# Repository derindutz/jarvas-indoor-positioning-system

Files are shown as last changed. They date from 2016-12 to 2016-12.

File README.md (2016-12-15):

# JARVAS Indoor Positioning System

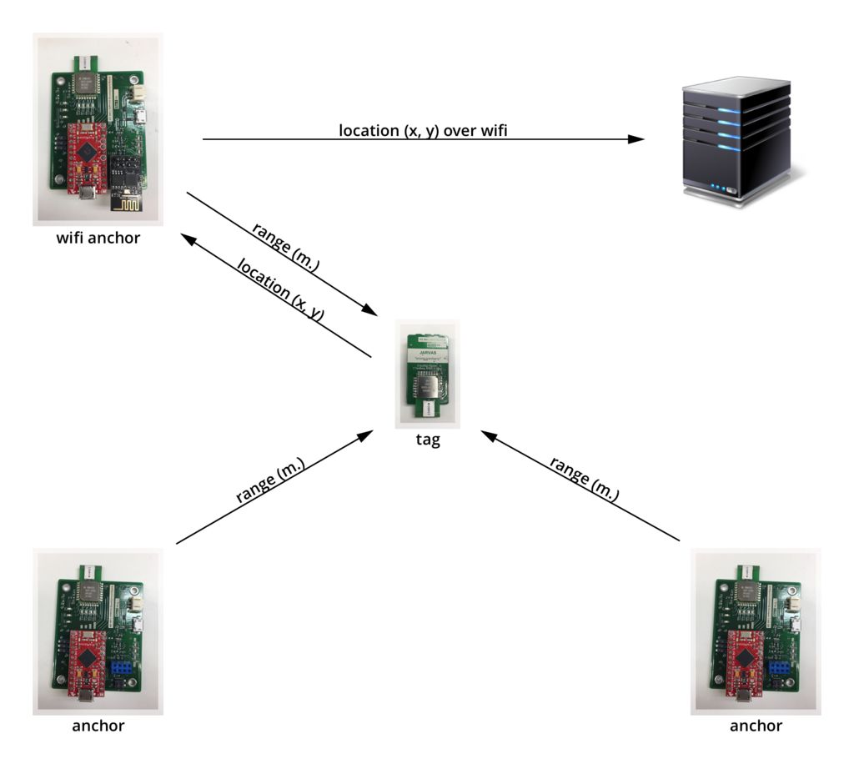
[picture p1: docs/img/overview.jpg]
JARVAS System


JARVAS (Just A Rather Very Average System) is an indoor positioning system, in which a wearable tag communicates with multiple stationary anchors to determine its position.

## How to Build It

Our primary documentation for how to re-create our setup lives on [Instructables](https://www.instructables.com/id/JARVAS-Indoor-Positioning-System/).

## Source Files

All of our source files (including software, PCB design files, and MATLAB simulation code) live in our [GitHub repository](https://github.com/dddutz/jarvas-indoor-positioning-system/).

## Technical Details

This website documents some of the more interesting technical aspects of the project. If you're looking to modify, extend, or get inspiration from what we did, read on.

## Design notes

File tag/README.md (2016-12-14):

# Tag

## Instructions

1. Connect the tag to your computer.
2. Open the .ino file in the Arduino app.
3. Upload the code.

##CALIBRATION IS IMPORTANT!

1. Make sure you know which anchors have which addresses.
2. Set CALIBRATION_FIRST to true.
3. Place each anchor 2 meters away from the tag. Make sure to keep anchors away from each other as much as possible.
4. Record each of the anchor's distance values, and record them in BEACON_N_FIRSTDIST.
5. Repeat this process, but at 5 meters away from each tag, and recording in BEACON_N_SECONDDIST.
5. Set CALIBRATION_FIRST to false.
6. Your tag is now calibrated!

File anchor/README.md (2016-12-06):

# Anchor

## Instructions
1. Connect a non-wifi anchor to your computer.
2. Open the .ino file in the Arduino app.
3. Upload the code.

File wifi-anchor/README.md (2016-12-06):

# Wifi Anchor

## Instructions
1. Connect the wifi anchor to your computer.
2. Open the .ino file in the Arduino app.
3. Upload the code.

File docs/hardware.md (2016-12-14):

# JARVAS Hardware

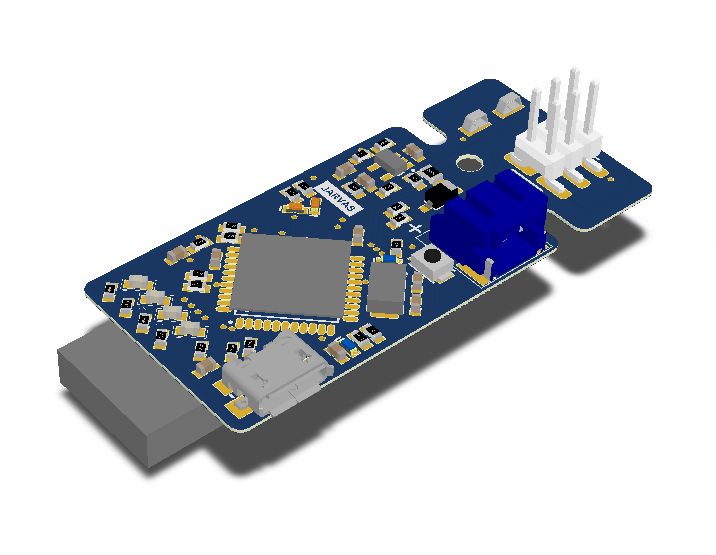
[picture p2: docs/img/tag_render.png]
JARVAS Tag
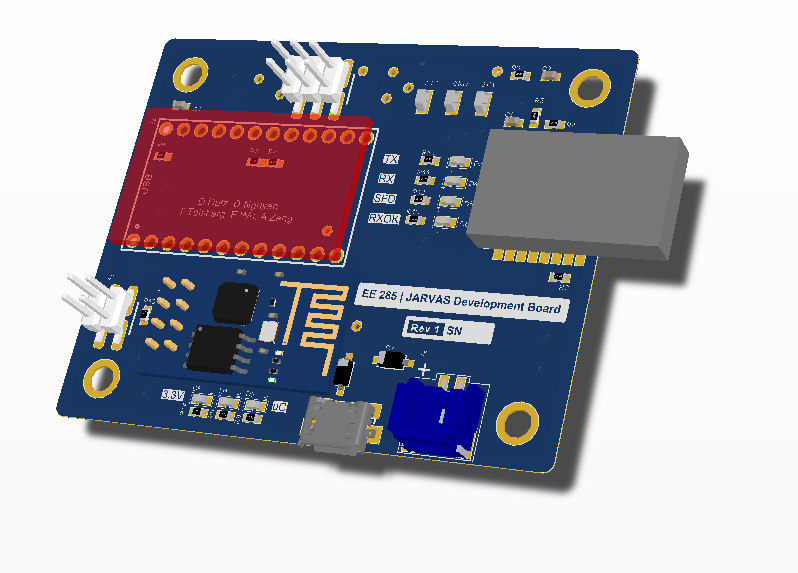
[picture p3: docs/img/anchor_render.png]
JARVAS Anchor


The core of the JARVAS system is the DWM1000 (
[product page](http://www.decawave.com/products/dwm1000-module),
[datasheet](http://www.decawave.com/sites/default/files/resources/dwm1000-datasheet-v1.3.pdf)
) radio module, an ultra wideband transciever module optimized for time of
flight ranging systems, and the Atmega32U4 processor.

There are two versions of the JARVAS hardware: a base station board that
supports WiFi (using an
[ESP8266](https://nurdspace.nl/images/e/e0/ESP8266_Specifications_English.pdf)
) and is designed for easy debugging, and a small, low-cost tag module.
The system requires at least one of the anchors have WiFi support so transmit
location data to a server, however all other anchors and tags in the system
may use either the larger base station board or the small tag board.

## The Tag

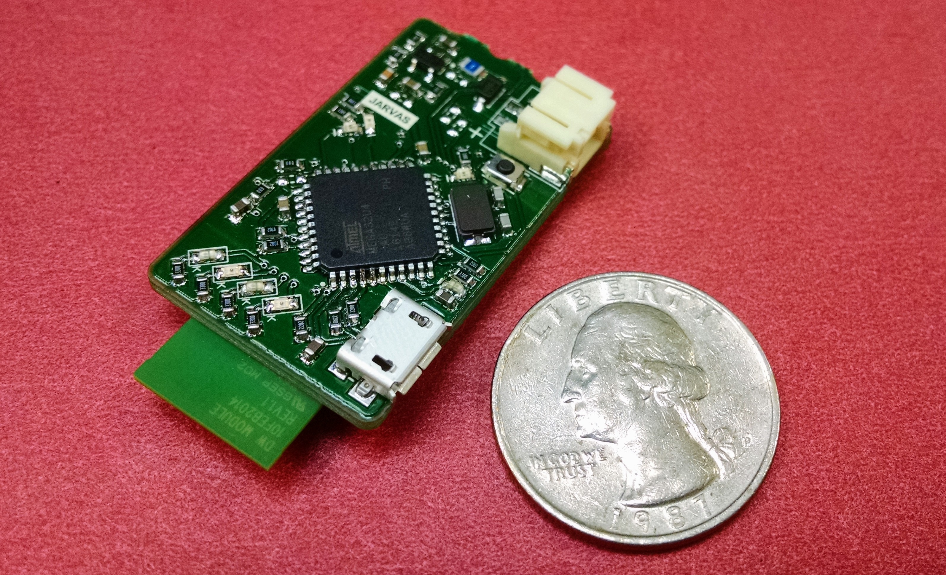
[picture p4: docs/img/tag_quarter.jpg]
JARVAS Tag PCB


The tag board hosts an Atmega32U4, a single-cell LiPo/Li-Ion connector, a few
debugging LEDs, and the DWM1000 radio module. It is essentially a
purpose-built version of the popular [SparkFun Pro Micro](https://www.sparkfun.com/products/12587)
or the [Adafruit Atmega32U4 breakout](https://www.adafruit.com/product/296)
with a DWM1000 module built in.

In total, it measures 1.5"x0.9" without the programming tag.

Note that while we call this this "tag", it is completely capable of being
used as an anchor as well, provided that there is at least one anchor in the
system which supports WiFi.

### Programming Header

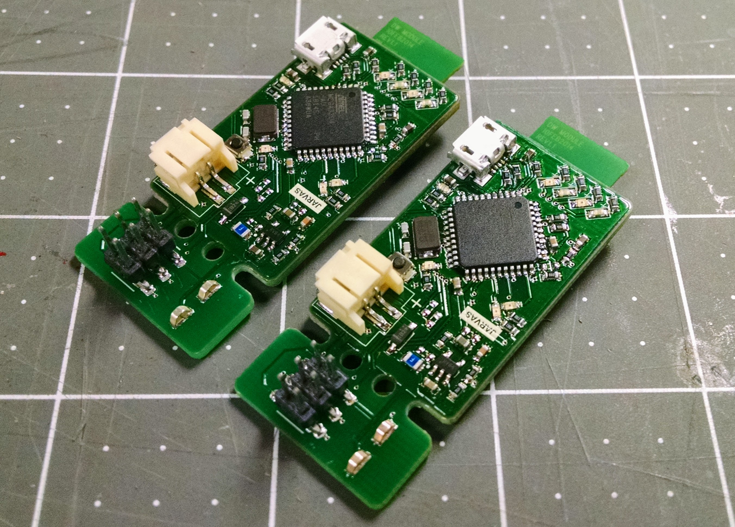
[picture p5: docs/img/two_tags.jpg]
Tags with their programming headers


The tag comes with a break-away section for initial programming. The
section at the top contains test points for the 3.3 V and GND rails and an
ICSP header. This ICSP header can be used to program the Atmega32U4. If you
choose to install the Arduino firmware, as described [here](firmware),
you can program this board directly over USB through the Arduino software.
Once you verify that everythings is working, this top section can be broken
off to reduce the size and height of the PCB.

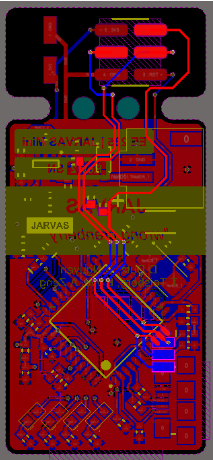
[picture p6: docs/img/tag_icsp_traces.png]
ICSP traces


## The Anchor

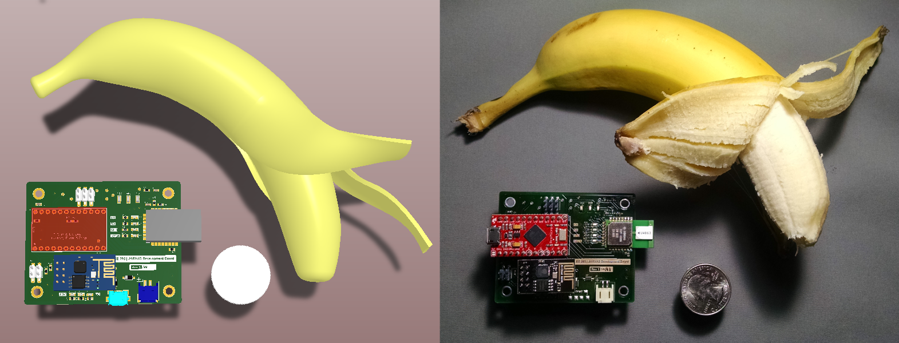
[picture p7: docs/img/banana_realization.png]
An anchor board next to a render


The anchor is the larger, more debug-friendly, and WiFi-supporting version.
It is extremely similar to the tag except for the addition of an ESP8266 WiFi
Module and using an off-the-shelf Arduino Pro Micro instead of having an
Atmega32U4 on-board. This means that no programmer is required to get this
board up and running. The downside, though, is that it is significantly larger
and costs more.

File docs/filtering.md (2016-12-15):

# Filtering

In our testing, we found the ranging data to be quite noisy. With only three anchors, the linear least squares algorithm is quite noise sensitive. As such, some filtering on the ranging data is necessary.

The [Arduino DWM1000 library](https://github.com/thotro/arduino-dw1000) by thotro has a built-in (exponential moving average](https://en.wikipedia.org/wiki/Moving_average#Exponential_moving_average) filter that can be enabled with a single call to `DW1000Ranging.useRangeFilter(true);`. This is a very computationally low-cost choice and definitely a good place to start.

Early on, we took some raw data from pairs of DWM1000 modules in various locations. An example of this data is below:

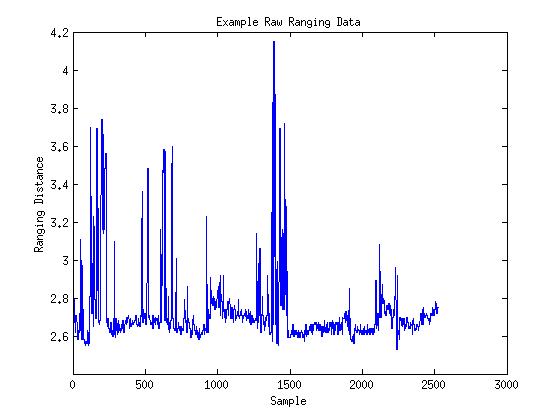
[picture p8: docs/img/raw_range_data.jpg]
Raw ranging data


As you can see, the noise is dominated by sharp peaks lasting only a sample or two. For this type of noise, a median filter is often a more effective choice. While any kind of moving average filter is always going to be affected at least a little by an extremely out of range value, a median filter will allow such valus to slide through without changing output.

Shown below are the results of a simple median filter overlayed in red against another raw data set in black.

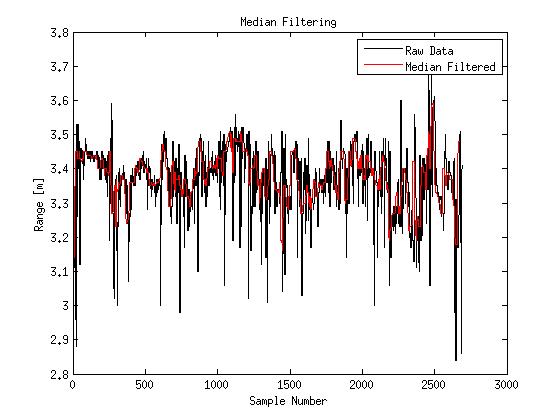
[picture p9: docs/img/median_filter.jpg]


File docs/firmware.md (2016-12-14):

# Programming Arduino Firmware on an Atmega32U4

This page is not really specific to this project and should be useful to anyone trying to program Arduino firmware onto an [Atmega32U4](http://www.atmel.com/Images/Atmel-7766-8-bit-AVR-ATmega16U4-32U4_Datasheet.pdf) chip.

## What you'll need

You will need:

* An ICSP programmer (such as the [JTAGICE3](http://www.atmel.com/tools/jtagice3.aspx))
* The [avrdude](http://www.nongnu.org/avrdude/) software
* Firmware for the chip. We used SparkFun's [Caterina](https://cdn.sparkfun.com/datasheets/Dev/Arduino/Boards/32U4Note.pdf) bootloader (Caterina-promicro8.bin from [here](https://github.com/sparkfun/Arduino_Boards/tree/master/sparkfun/avr/bootloaders/caterina))
* A board with an Atmega32U4 and an ICSP header, such as our [Tag Board](../hardware/#the-tag)

### Tip for Linux users

You may need to setup port permission for your programmer. For the JTAGICE3, you'll need to create a `/etc/udev/rules.d/98-local-jtagice3.rules` file with the following line:

```
SUBSYSTEM=="usb", ATTRS{idVendor}=="03eb", ATTRS{idProduct}=="2140", GROUP="dialout"
```

Also, be sure your user is in the `dialout` group.

## Instructions

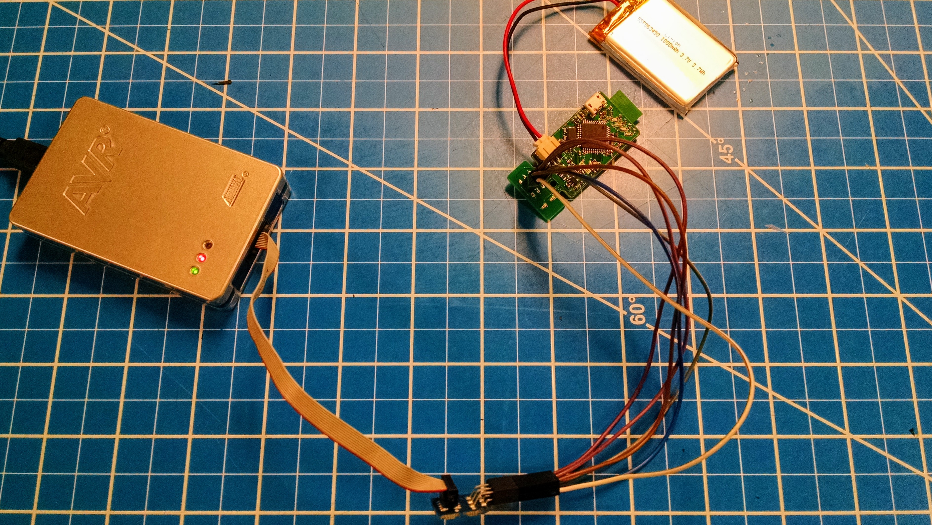
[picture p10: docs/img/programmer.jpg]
JTAGICE3 programmer hooked up to JARVAS tag board


### Step 1: Hook up your programmer

Connect your programmer to the ICSP header on your board. Double check the pinouts and orientations (many ICSP connectors are not keyed) before powering things up.

Remember that your programmer generally does not supply power to the board, so you'll need to supply that yourself.

### Step 2: Test the connection

The following command will read the three sets of fuse bits from the microcontroller and write the values to three text files on your system:

```
avrdude -v -pm32u4 -cjtag3isp -Pusb -B22 -U efuse:r:efuse.hex:h -U hfuse:r:hfuse.hex:h -U lfuse:r:lfuse.hex:h
```

You should get some output that ends with:

```
avrdude: safemode: hfuse reads as 99
avrdude: safemode: efuse reads as F3
avrdude: safemode: Fuses OK (E:F3, H:99, L:5E)

avrdude done.  Thank you.
```

### Step 3: Programming

With the firmware file placed in your working directory, run the following command to set the fuse bits and program your chip:

```
avrdude -v -pm32u4 -cjtag3isp -Pusb -B22 -U flash:w:Caterina-promicro8.hex -U hfuse:w:0xd8:m -U lfuse:w:0xff:m -U efuse:w:0xfe:m
```

It may fail to write the efuse. If prompted, answer 'y' to retry. If it fails, don't worry.

### Step 4: Try it!

Plug your board into your computer over USB and program it with the Arduino software.

## Notes and References

The above commands assume you're using a JTAGICE3 programmer to program an Atmega32U4 clocekd at 8 MHz with a 3.3V supply voltage. If any of those things are not quite the same for you, you'll have to adjust things a bit.

You can find fuse bit settings that go along with the various SparkFun firmwares on [their repository](https://github.com/sparkfun/Arduino_Boards/blob/master/sparkfun/avr/bootloaders/caterina/program.txt).

### Useful References

* [Fuse bit calculator](http://www.engbedded.com/fusecalc/)
* [JTAGICE3 Pinout](http://www.atmel.com/webdoc/jtagice3/jtagice3.using_ocd_physical_spi.html#jtagice3.spi_header_pinout)
* [AVRDUDE Refernce](http://www.nongnu.org/avrdude/user-manual/avrdude_4.html)
* A [blog post](http://electronut.in/bootloader-atmega32u4/) from someone else who has done this

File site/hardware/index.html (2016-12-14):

- Docs »
- Hardware

# JARVAS Hardware

JARVAS Tag JARVAS Anchor

The core of the JARVAS system is the DWM1000 ( product page (http://www.decawave.com/products/dwm1000-module), datasheet (http://www.decawave.com/sites/default/files/resources/dwm1000-datasheet-v1.3.pdf) ) radio module, an ultra wideband transciever module optimized for time of flight ranging systems, and the Atmega32U4 processor.

There are two versions of the JARVAS hardware: a base station board that supports WiFi (using an ESP8266 (https://nurdspace.nl/images/e/e0/ESP8266_Specifications_English.pdf) ) and is designed for easy debugging, and a small, low-cost tag module. The system requires at least one of the anchors have WiFi support so transmit location data to a server, however all other anchors and tags in the system may use either the larger base station board or the small tag board.

## The Tag



The tag board hosts an Atmega32U4, a single-cell LiPo/Li-Ion connector, a few debugging LEDs, and the DWM1000 radio module. It is essentially a purpose-built version of the popular SparkFun Pro Micro (https://www.sparkfun.com/products/12587) or the Adafruit Atmega32U4 breakout (https://www.adafruit.com/product/296) with a DWM1000 module built in.

In total, it measures 1.5"x0.9" without the programming tag.

Note that while we call this this "tag", it is completely capable of being used as an anchor as well, provided that there is at least one anchor in the system which supports WiFi.

### Programming Header



The tag comes with a break-away section for initial programming. The section at the top contains test points for the 3.3 V and GND rails and an ICSP header. This ICSP header can be used to program the Atmega32U4. If you choose to install the Arduino firmware, as described here, you can program this board directly over USB through the Arduino software. Once you verify that everythings is working, this top section can be broken off to reduce the size and height of the PCB.



## The Anchor



The anchor is the larger, more debug-friendly, and WiFi-supporting version. It is extremely similar to the tag except for the addition of an ESP8266 WiFi Module and using an off-the-shelf Arduino Pro Micro instead of having an Atmega32U4 on-board. This means that no programmer is required to get this board up and running. The downside, though, is that it is significantly larger and costs more.

Next Previous

Built with MkDocs (http://www.mkdocs.org) using a theme (https://github.com/snide/sphinx_rtd_theme) provided by Read the Docs (https://readthedocs.org).

« Previous Next »

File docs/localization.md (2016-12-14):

# Localization

JARVAS estimates your position using a linear least squares algorithm based
on time of flight ranging data. On this page, we will break down how this
works in detail.

Imagine you are on a ship and can see a single lighthouse in the distance. 
Let's say you can tell the distance to this lighthouse but nothing else.
If you were looking at a map and knew the location of the lighthouse, you
could draw a circle around the lighthouse and know that you were somewhere
along the circle.

Now let's say you can see a second lighthouse and also your know distance to 
it (but not, let's pretend, the angle between the two lighthouses). Now you
have two circles you can draw. Assuming the two lighthouses are in different
locations, the circles will overlap in one or two locations. Finally, by
adding a third lighthouse, you can figure out which point you are at.

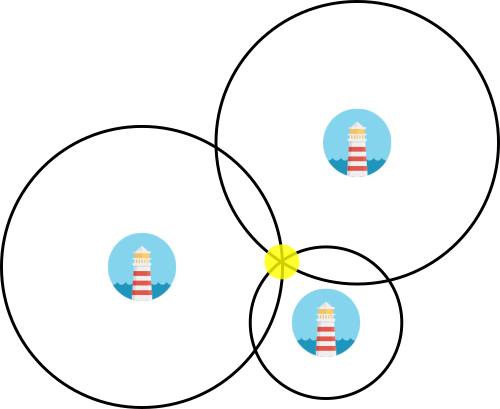
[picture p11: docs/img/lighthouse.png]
Illustration of the light house analogy


Derived from image by pixelbuddha [CC BY 3.0 (http://creativecommons.org/licenses/by/3.0)], via Wikimedia Commons

## Linear Least Squares Estimation

If you aren't familiar with linear least squares estimation, we recommend some
background reading before jumping into this:

[Wikipedia: Linear Least Squares](https://en.wikipedia.org/wiki/Linear_least_squares_(mathematics))

[Stanford Linear Algebra Course Notes](http://ee263.stanford.edu/lectures/ls.pdf)

Our linearized technique is based on the first method described in 
"Linear least squares localization in sensor networks" by Yue Wang (DOI: 
[10.1186/s13638-015-0298-1](http://link.springer.com/article/10.1186/s13638-015-0298-1)).

In general, localization based on a set of distances in a non-linear problem,
however there are linear approximtaions that work quite well.

Each anchor has some known position \((x_i,y_i\) and is can measure a distance
\(\hat{d_i}\) to the tag. For a single anchor \(i\) ranging to a tag at
position \((x,y)\), this
gives us the simple geometric equation:

$$ (x-x_i)^2+(y-y_i)^2=d_i^2 $$

We can then re-arrange this expression as follows:

$$ x^2-2xx_i+x_i^2+y^2-2yy_i+y_i^2=\hat{d}_i^2 \\
-2xx_i - 2yy_i + (x^2+y^2) = \hat{d}_i^2 - x_i^2 - y_i^2 $$

We have three (or more) anchors, so we can write at least three of these
equations. Written in matrix form, we have:

$$
\begin{bmatrix}
-2x_1 & -2y_1 & 1 \\
-2x_2 & -2y_2 & 1 \\
-2x_3 & -2y_3 & 1
\end{bmatrix}
\begin{bmatrix}
x \\
y \\
x^2 + y^2
\end{bmatrix}
=
\begin{bmatrix}
\hat{d}_1^2-x_1^2-y_1^2 \\
\hat{d}_2^2-x_2^2-y_2^2 \\
\hat{d}_3^2-x_3^2-y_3^2
\end{bmatrix}
$$

This gives us the standard form:

$$
\begin{bmatrix}
x \\
y \\
x^2 + y^2
\end{bmatrix}_{ls}
=
\begin{bmatrix}
-2x_1 & -2y_1 & 1 \\
-2x_2 & -2y_2 & 1 \\
-2x_3 & -2y_3 & 1
\end{bmatrix}^\dagger
\begin{bmatrix}
\hat{d}_1^2-x_1^2-y_1^2 \\
\hat{d}_2^2-x_2^2-y_2^2 \\
\hat{d}_3^2-x_3^2-y_3^2
\end{bmatrix}
$$

The left side of the equation is what we want to solve for. Specifically, we are interested in the first two terms of the vector: \(x\) and \(y\).

On the right, the large matrix that we have to take the 
[pseudo-inverse](https://en.wikipedia.org/wiki/Moore%E2%80%93Penrose_pseudoinverse)
of is a function only of the configuration of the system. It changes only if the anchors move, not if the tag moves. This is very important because taking the pseudo-inverse requires a non-trivial number of computations, especially as you start adding more anchors.

At runtime, this works out to be a single matrix-vector multiplication of a 3x3 by a 3x1.

## MATLAB Implementation

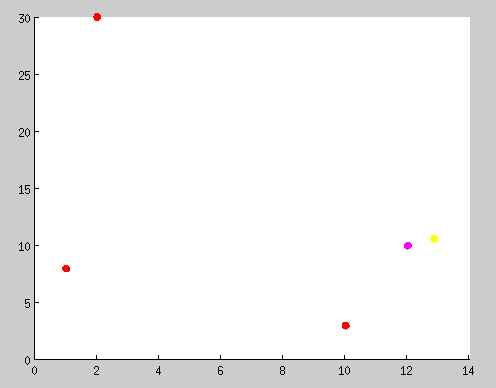
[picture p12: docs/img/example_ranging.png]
Screenshot of MATLAB simulation


In order to test this algorith, we created a MATLAB script that takes in a set of positions and ranges and outputs a graph of the real and estimated location of the tag. If you are intersted in extending this project to use any of several possible better linearized algorithms, this MATLAB script would be a good starting point.

You can find the two MATLAB files `rangepositioning.m` and `plotposition.m` in the [simulation folder](https://github.com/dddutz/jarvas-indoor-positioning-system/tree/master/simulation) of our repository.

## C Implementation

In the JARVAS system, this processing is run on the tag iself. The C implementaiton of this algorithm uses the Arduino MatrixMath library and lives in the [tag sketch](https://github.com/dddutz/jarvas-indoor-positioning-system/blob/master/tag/tag.ino).

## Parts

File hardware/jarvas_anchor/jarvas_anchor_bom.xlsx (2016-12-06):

Description | Customer Refernce | Quantity Per Board | Order Quantity (for 4 boards) | Supplier 1 | Supplier Part Number 1
PC TEST POINT MINIATURE SMT | 3V3, GND, VCC | 3 | 12 | Digi-Key | 5015KCT-ND
 | C1, C2, C3, C4, C7 | 5 | 20 | Digi-Key | 587-1251-1-ND
 | C5 | 1 | 4 | Digi-Key | 587-1441-1-ND
 | C6 | 1 | 4 | Digi-Key | 399-1092-1-ND
Orange 605nm LED Indication - Discrete 2V 0603 (1608 Metric) | D1, D2, D3, D4, D5, D6, D8 | 7 | 28 | Digi-Key | 160-1434-1-ND
DIODE SCHOTTKY 0.5A 20V SOD-123 | D7, D9 | 2 | 8 | Digi-Key | MBR0520LCT-ND
CONN HEADER PH SIDE 2POS 2MM SMD | J2 | 1 | 4 | Digi-Key | 455-1749-1-ND
RF TXRX MODULE WIFI TRACE ANT | J3 | 1 | 4 | Digi-Key | 1568-1235-ND
CONN RCPT MICRO USB AB SMD R/A | J4 | 1 | 4 | Digi-Key | H125279CT-ND
CONN HEADER 6POS .100" VERT TIN | J5 | 1 | 4 | Digi-Key | WM17449-ND
CONN HEADER 4POS .100" VERT TIN | J6 | 1 | 4 | Digi-Key | WM9514-ND
RES SMD 0.0 OHM | R1, R3, R4, R5, R15, R16, R17, R18, R19, R20, R21, R22 | 12 | 48 | Digi-Key | 541-0.0GCT-ND
RES SMD 22K OHM 1% 1/10W 0603 | R2 | 1 | 4 | Digi-Key | 541-22.0KHCT-ND
RES SMD 47K OHM 1% 1/10W 0603 | R6, R7 | 2 | 8 | Digi-Key | 541-47.0KHCT-ND
RES SMD 330 OHM 1% 1/10W 0603 | R8, R9, R10, R11, R12, R13, R14 | 7 | 28 | Digi-Key | 541-330HCT-ND
Linear Voltage Regulator IC Positive Fixed 1 Output 3.3V 500mA TSOT-23-5 | U2 | 1 | 4 | Digi-Key | CAT6219-330TDGT3CT-ND
12 Pin Female Header | J1 | 2 | 8 | Digi-Key | 609-3553-ND
SparkFun Arduino Pro Micro | Pro Micro | 1 | 4 | Digi-Key | 1568-1061-ND
Solder Paste | PASTE | 1 | 1 | Digi-Key | SMD291AX50T3-ND

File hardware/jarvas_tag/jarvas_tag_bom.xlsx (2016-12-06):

Comment | Description | Designator | Per Board | Supplier Part Number | Order Quantity | Customer Reference
TEST_KEYSTONE5015 | PC TEST POINT MINIATURE SMT | 3V3, GND | 2 | 5015KCT-ND | 8 | Jarvas Mini 3V3, GND
__template_cap |  | C1, C2, C3, C6, C10 | 5 | 587-1251-1-ND | 20 | Jarvas Mini C1, C2, C3, C6, C10
__template_cap |  | C4 | 1 | 587-1441-1-ND | 4 | Jarvas Mini C4
__template_cap |  | C5 | 1 | 399-1092-1-ND | 4 | Jarvas Mini C5
__template_cap |  | C7 | 1 | 478-1251-1-ND | 4 | Jarvas Mini C7
CAP_CER_8PF_100V |  | C8, C9 | 2 | 478-3697-1-ND | 8 | Jarvas Mini C8, C9
LED | Green LED | D1, D2, D6, D7, D8, D9 | 6 | LTST-C191KGKT | 24 | Jarvas Mini D1, D2, D6, D7, D8, D9
LED_LBQ39G_BLUE | Blue 470nm LED Indication - Discrete 2.85V 0603 (1608 Metric) | D3, D4 | 2 | 475-2816-1-ND | 8 | Jarvas Mini D3, D4
SCHOTTKY_MBR0520L | DIODE SCHOTTKY 0.5A 20V SOD-123 | D5 | 1 | MBR0520LCT-ND | 4 | Jarvas Mini D5
FAST_MFU0805.50CT-ND | FUSE .50A 0805 VFAST SMD | F1 | 2 | MFU0805.50CT-ND | 8 | Jarvas Mini F1
CONN_USB_MICROAB_SMD_R/A | CONN RCPT MICRO USB AB SMD R/A | J1 | 1 | H125279CT-ND | 4 | Jarvas Mini J1
CONN JST 2POS SMD | CONN HEADER PH SIDE 2POS 2MM SMD | J2 | 1 | 455-1749-1-ND | 4 | Jarvas Mini J2
CONN_2x3_15-91-2060 | CONN HEADER 6POS .100" VERT TIN | J3 | 1 | WM17449-ND | 4 | Jarvas Mini J3
__template_resistor | RES SMD 47K OHM 1% 1/10W 0603 | R1, R6, R8 | 3 | 541-47.0KHCT-ND | 12 | Jarvas Mini R1, R6, R8
__template_resistor | RES SMD 10K OHM 1% 1/10W 0603 | R2, R13 | 2 | 541-10.0KHCT-ND | 8 | Jarvas Mini R2, R13
__template_resistor | RES SMD 0.0 OHM | R3, R4, R5, R7, R17 | 5 | 541-0.0GCT-ND | 20 | Jarvas Mini R3, R4, R5, R7, R17
__template_resistor | RES SMD 330 OHM 1% 1/10W 0603 | R9, R10, R14, R15, R18, R19, R20, R21 | 8 | 541-330HCT-ND | 32 | Jarvas Mini R9, R10, R14, R15, R18, R19, R20, R21
__template_resistor | RES SMD 22 OHM 1% 1/10W 0603 | R11, R12, R22, R23, R24 | 5 | 541-22.0HCT-ND | 20 | Jarvas Mini R11, R12, R22, R23, R24
__template_resistor | RES SMD 22K OHM 1% 1/10W 0603 | R16 | 1 | 541-22.0KHCT-ND | 4 | Jarvas Mini R16
SWITCH_SPST-NO | SWITCH TACTILE SPST-NO 0.05A 12V | SW1 | 1 | SW1020CT-ND | 4 | Jarvas Mini SW1
MCU_ATMEGA32U4 | IC MCU 8BIT 32KB FLASH 44TQFP | U1 | 1 | ATMEGA32U4-AURCT-ND | 4 | Jarvas Mini U1
3.3V LDO | Linear Voltage Regulator IC Positive Fixed 1 Output 3.3V 500mA TSOT-23-5 | U2 | 1 | CAT6219-330TDGT3CT-ND | 4 | Jarvas Mini U2
DWM1000 |  | U3 | 1 | 1479-1002-1-ND | 1 | Jarvas Mini U3
XTAL_NX5032GA | CRYSTAL 8.00 MHZ 8PF SMD | X1 | 1 | 644-1132-1-ND | 4 | Jarvas Mini X1

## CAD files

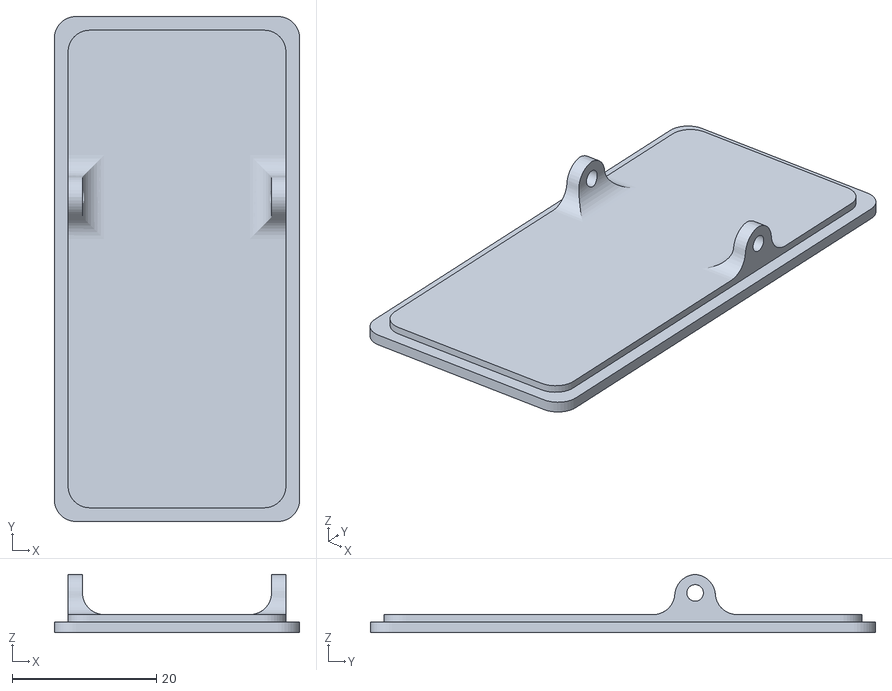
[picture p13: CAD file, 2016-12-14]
3D Files/jarvas_box lid.STL
34.0 x 70.0 x 8.07

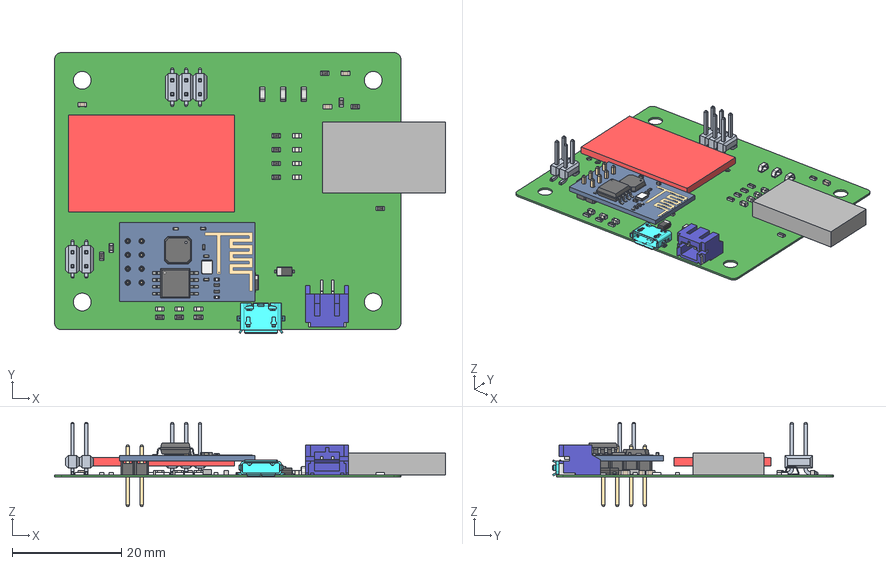
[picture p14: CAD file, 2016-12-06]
hardware/jarvas_anchor/jarvas_anchor_cad.step
71.7 x 51.5 x 15.4 mm
Board
ZX62-AB-5PA
User_Library-Wi07C
keystone5015 x 3
Extruded x 24
CircuitWorks-SOD123 x 2
S2B-PH-SM4-TB

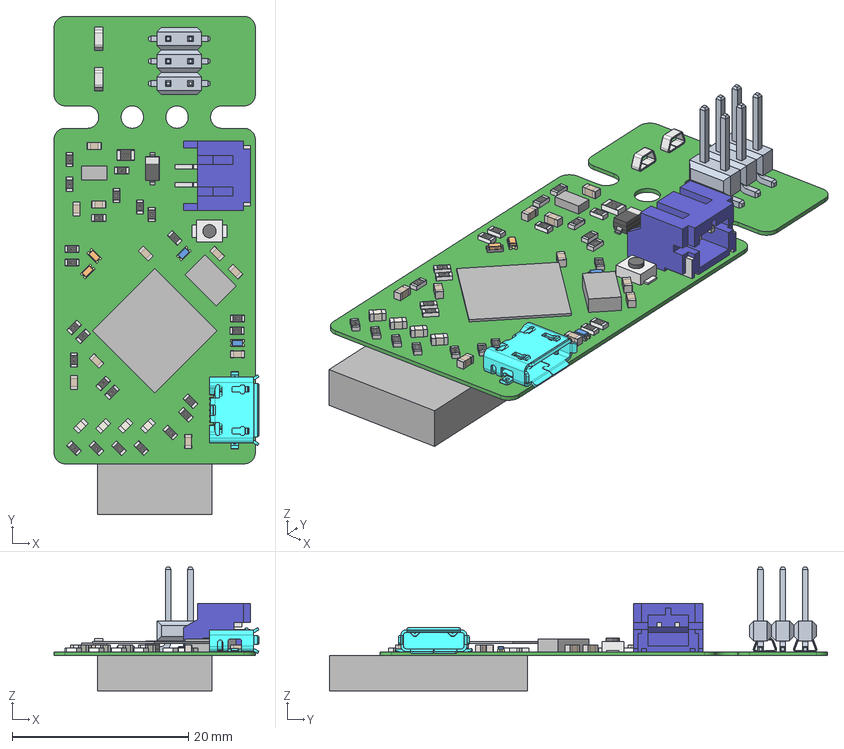
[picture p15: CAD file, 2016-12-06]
hardware/jarvas_tag/jarvas_tag_cad.step
23.3 x 56.6 x 14.1 mm
Board
keystone5015 x 2
User_Library-led_0603_(4) x 2
User_Library-led_0603_(2) x 2
CircuitWorks-SOD123
Extruded x 16
ZX62-AB-5PA
S2B-PH-SM4-TB
b3u-1000p

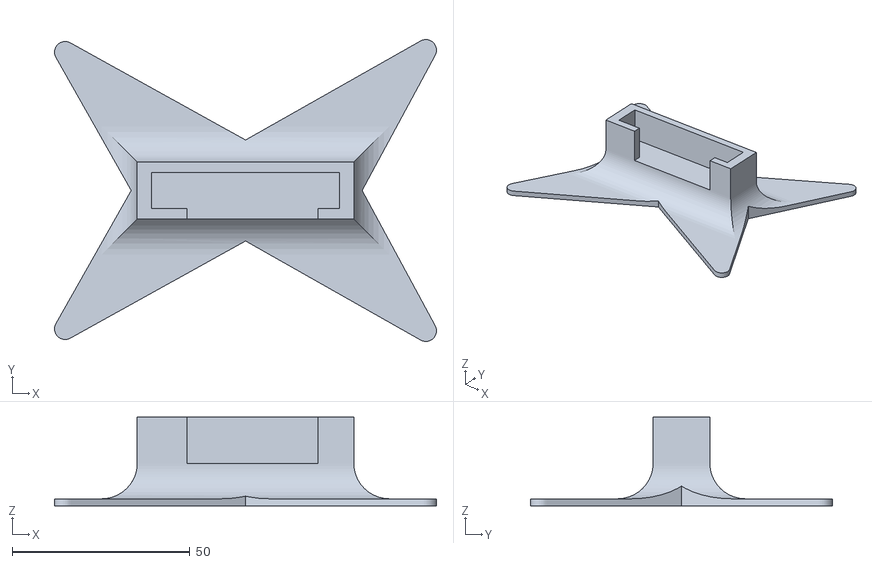
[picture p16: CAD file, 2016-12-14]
3D Files/jarvas_stand.STL
107.6 x 85.0 x 25.0

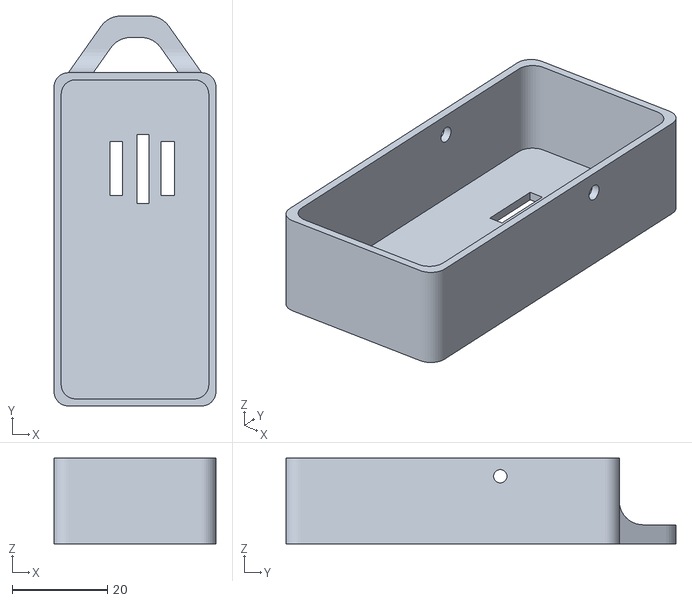
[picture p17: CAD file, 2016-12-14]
3D Files/jarvas_box.STL
34.0 x 81.9 x 18.0

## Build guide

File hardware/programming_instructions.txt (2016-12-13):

Programming the SparkFun Caterina bootloader onto an Atmega32U4
Written: 2016-11-14
Updated: 2016-12-13

This process probably needs to be optimized and refined, but the following appears to work. This was tested on Linux (Ubuntu 16.04), but should be portable to any platform.

If you are using a part other than the Atmega32U4 or a clock frequency other than 8 MHz, be sure to follow the instructions to download the correct firmware and find the correct fuse settings. If you are using a programmer other than the AVR JTAGICE3, be sure to update the "-cjtag3isp" argument.

*** Permissions ***

For Linux:
Create /etc/udev/rules.d/98-local-jtagice3.rules with the following line:
SUBSYSTEM=="usb", ATTRS{idVendor}=="03eb", ATTRS{idProduct}=="2140", GROUP="dialout"

*** Firmware ***

Get the firmware from here: https://github.com/sparkfun/Arduino_Boards/tree/master/sparkfun/avr/bootloaders/caterina
The correct one for an 8MHz Atmega32U4 is Caterina-promicro8.hex
The program.txt file has the fuse bit settings you need

*** Programming ***

Step 0: Read fuses to file
(This isn't technically necessary, but it's good just to confirm that you can talk to the chip.)
avrdude -v -pm32u4 -cjtag3isp -Pusb -B22 -U efuse:r:efuse.hex:h -U hfuse:r:hfuse.hex:h -U lfuse:r:lfuse.hex:h

Output should end with:
-----------------------------------------------------
avrdude: safemode: hfuse reads as 99
avrdude: safemode: efuse reads as F3
avrdude: safemode: Fuses OK (E:F3, H:99, L:5E)

avrdude done.  Thank you.
-----------------------------------------------------

It will also create three files in your working directory (efuse.hex, hfuse.hex, and lfuse.hex) that contain the current fuse settings. See fuse_bits_example/before for example output of this command before you configure the fuses in Step 1 (below) and fuse_bits_example/after for what you should have after Step 1.

Step 1:
avrdude -v -pm32u4 -cjtag3isp -Pusb -B22 -U flash:w:Caterina-promicro8.hex -U hfuse:w:0xd8:m -U lfuse:w:0xff:m -U efuse:w:0xfe:m
Answer 'y' at the prompt. Don't worry if it says the efuse could not be changed.

That's it!

*** Useful references ***

Looking up fuse bits: http://www.engbedded.com/fusecalc/
Someone else who did this: http://electronut.in/bootloader-atmega32u4/
AVRDUDE reference: http://www.nongnu.org/avrdude/user-manual/avrdude_4.html
JTAGICE3 SPI pinout: http://www.atmel.com/webdoc/jtagice3/jtagice3.using_ocd_physical_spi.html#jtagice3.spi_header_pinout

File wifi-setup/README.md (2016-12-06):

# Wifi Setup

## Instructions
1. Connect the wifi anchor to your computer.
2. Open the .ino file in the Arduino app.
3. Upload the code.
4. Once the code is uploaded, open the Serial Monitor.
5. Type AT into the Serial Monitor. You should see OK returned.
6. Type AT+CWMODE=1 into Serial. You should see OK returned.
7. Type AT+CWLAP into Serial. You should see a list of access points. Note that the ssid you want to use is in the list.
8. Type AT+CWJAP="ssid","pwd" where ssid is the one you want to use and pwd is the corresponding password.
9. Once you've recieved an IP, type AT+CIFSR. You should see a valid IP address returned.

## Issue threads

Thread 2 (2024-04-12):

using pcbway for assembly

ilker-aktuna, 2024-04-12:
Hi,

This is a very nice project and I would really like to use it at home for some smarthome projects.
But I am not good at assembling PCBs and my hands shake too much that I can't solder an element onto a PCB.
That's why a friend suggested me to use PCBway for assembly of the cards.
However, I am not familiar with building PCBs and PCBway has too many parameters in its turnkey solution.
Could you help me create an assembly project on PCBway ?
Or would you recommend another method for supplying the anchors and tags prebuilt ?

Thanks

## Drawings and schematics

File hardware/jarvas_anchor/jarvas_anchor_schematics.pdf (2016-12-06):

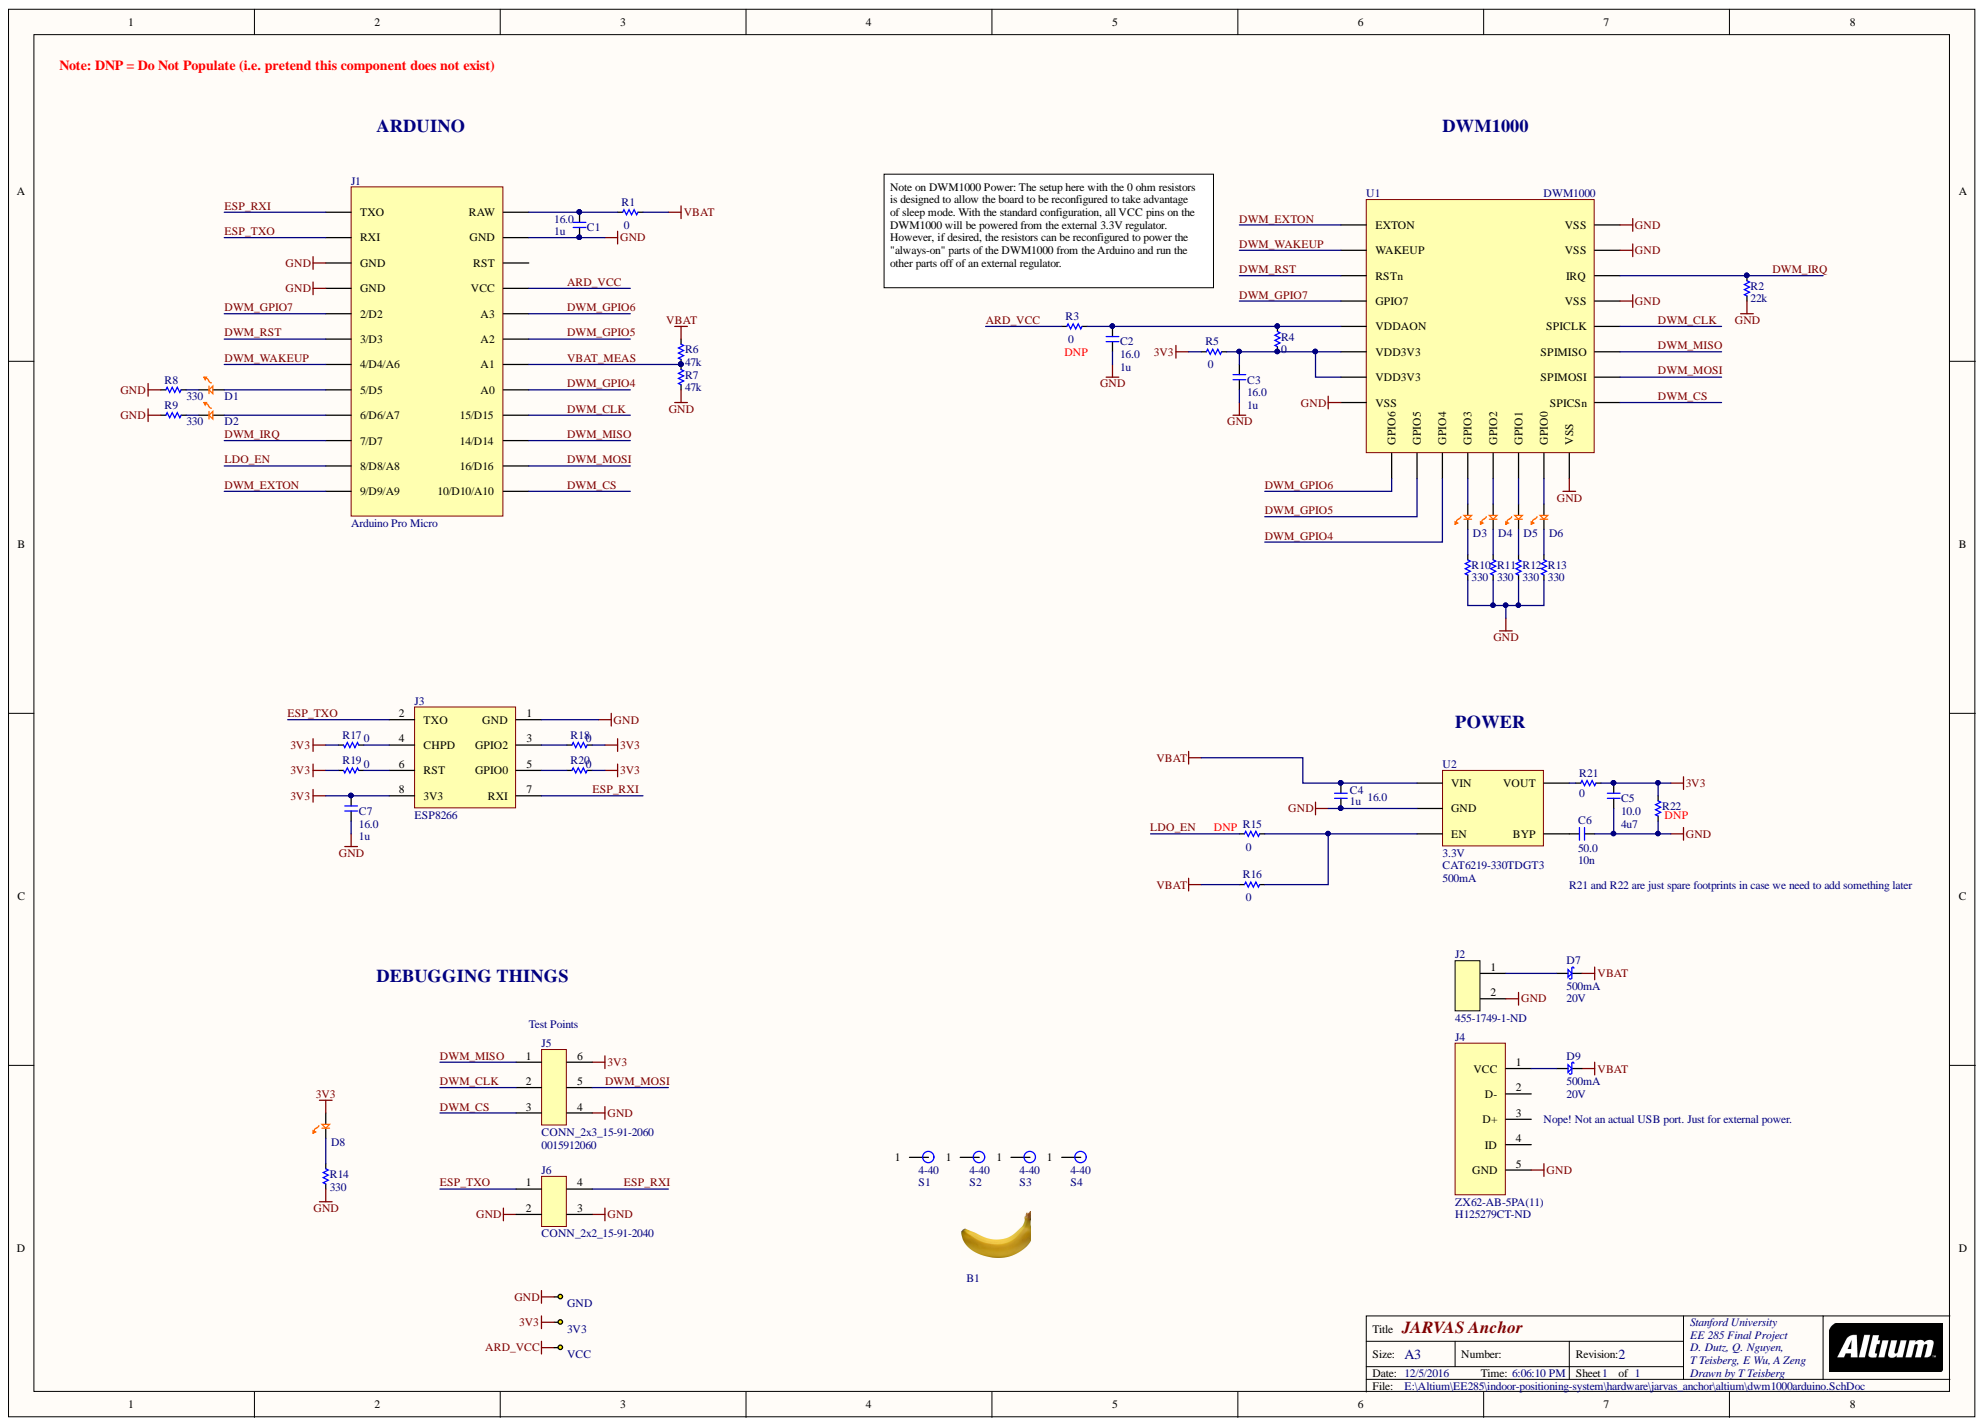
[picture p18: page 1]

Note: DNP = Do Not Populate (i.e. pretend this component does not exist)

Note on DWM1000 Power: The setup here with the 0 ohm resistors
is designed to allow the board to be reconfigured to take advantage
of sleep mode. With the standard configuration, all VCC pins on the
DWM1000 will be powered from the external 3.3V regulator.
However, if desired, the resistors can be reconfigured to power the
"always-on" parts of the DWM1000 from the Arduino and run the
other parts off of an external regulator.

R21 and R22 are just spare footprints in case we need to add something later

Nope! Not an actual USB port. Just for external power.

Title JARVAS Anchor | Stanford University EE 285 Final Project D. Dutz, Q. Nguyen, T Teisberg, E Wu, A Zeng Drawn by T Teisberg

Size: A3 | Number: | Revision: 2

Date: 12/5/2016 Time: 6:06:10 PM | | Sheet 1 of 1

E:\Altium\EE285\indoor-positioning-system\hardware\jarvas_anchor\altium\dwm1000arduino.SchDoc

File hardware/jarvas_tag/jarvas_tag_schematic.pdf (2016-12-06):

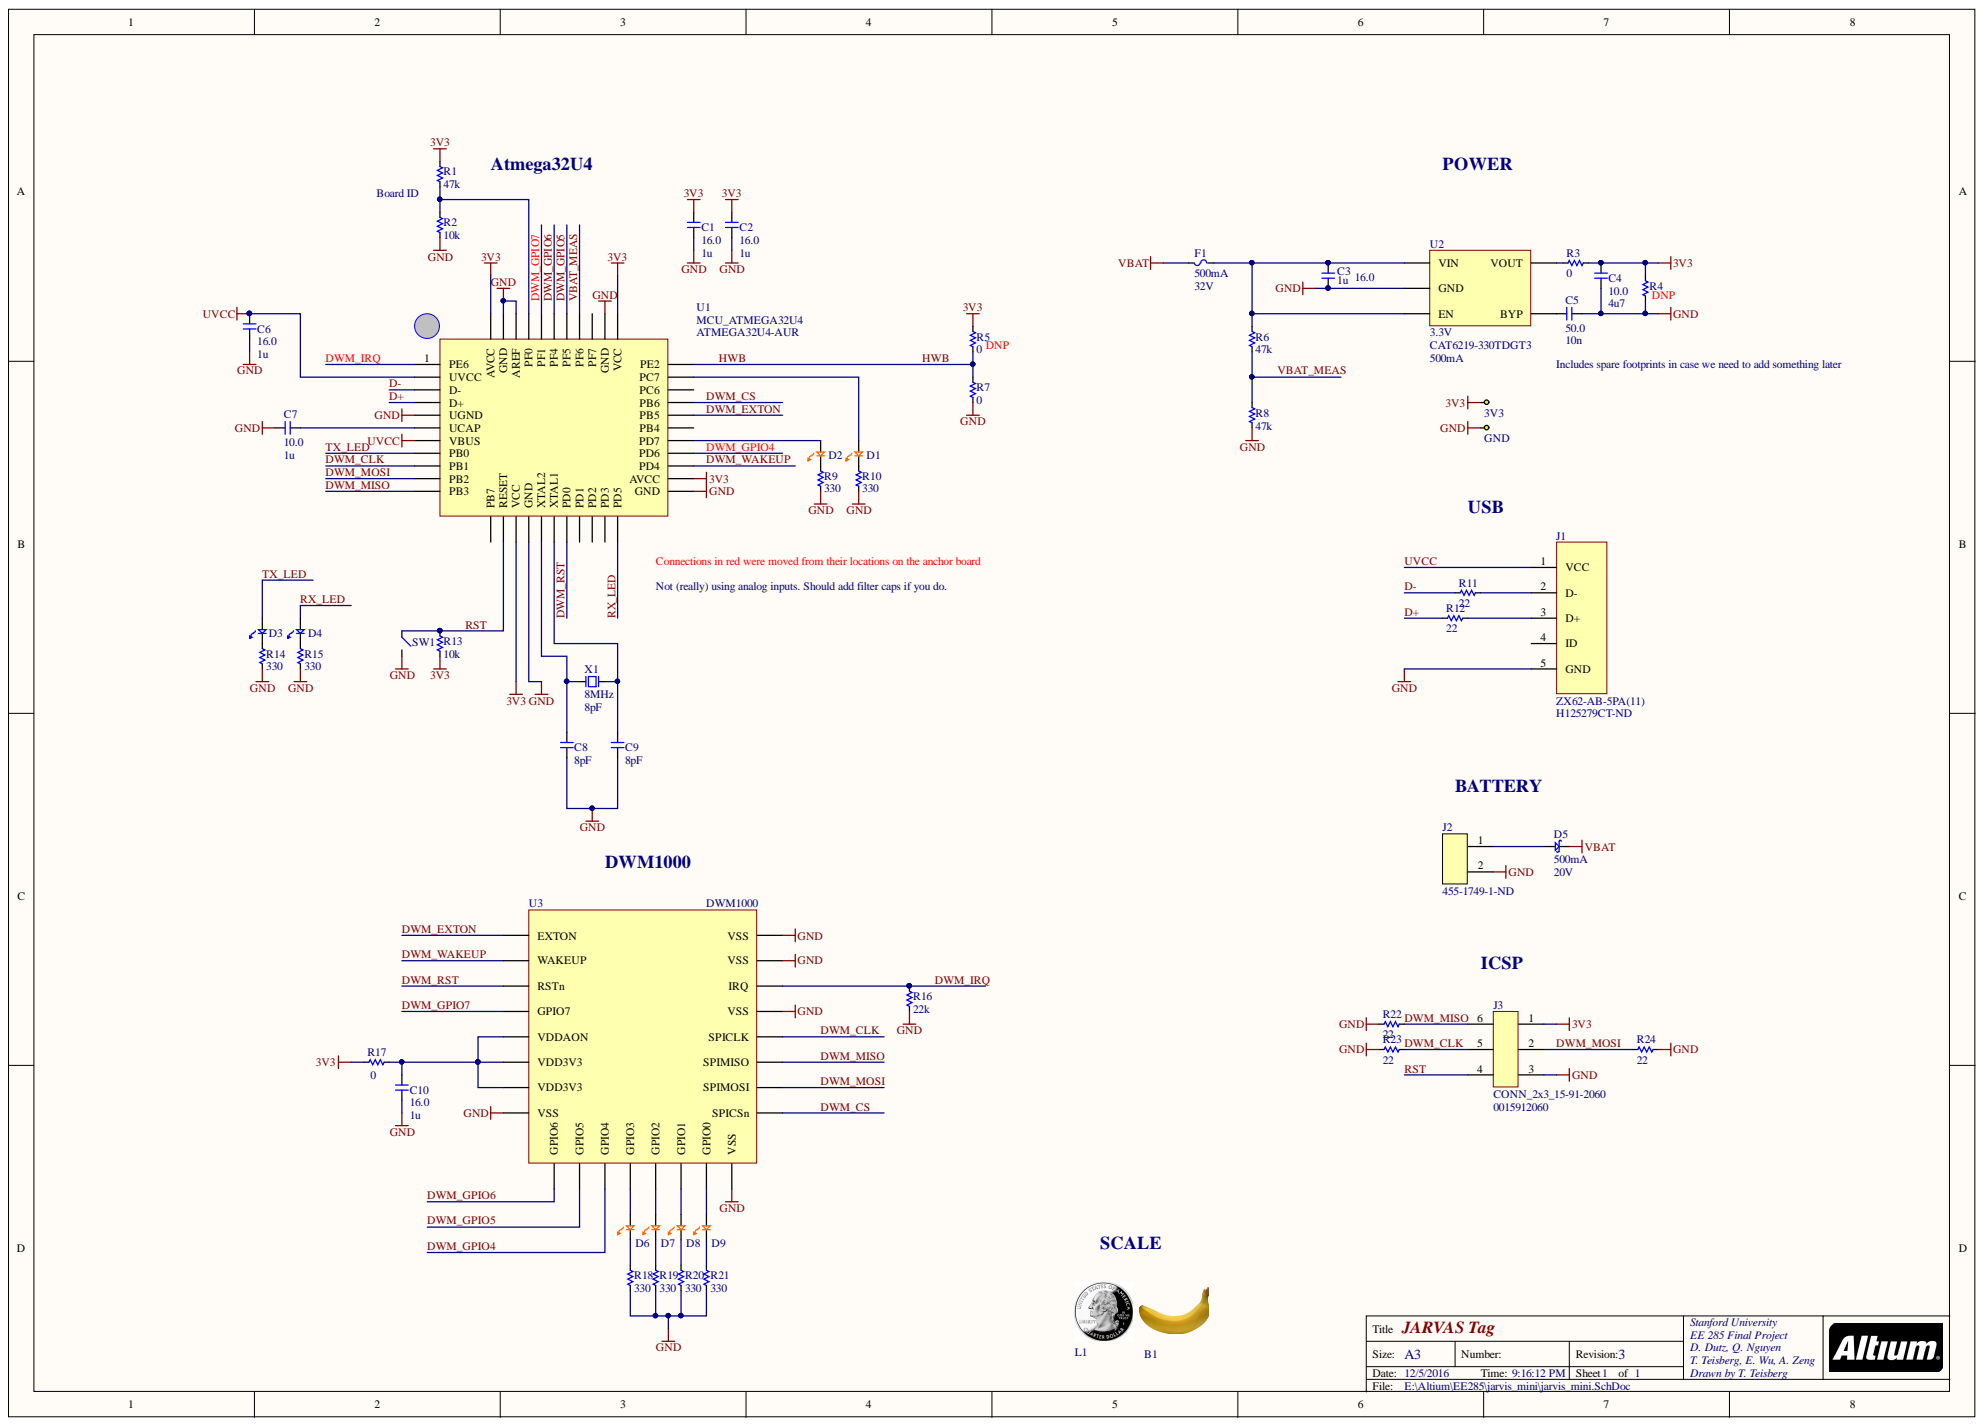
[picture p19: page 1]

Includes spare footprints in case we need to add something later

DWM_CS DWM_EXTON

DWM_WAKEUP

Connections in red were moved from their locations on the anchor board

Not (really) using analog inputs. Should add filter caps if you do.

Title JARVAS Tag | Stanford University EE 285 Final Project D. Dutz, Q. Nguyen T. Teisberg, E. Wu, A. Zeng Drawn by T. Teisberg

Size: A3 | Number: | Revision: 3

Date: 12/5/2016 Time: 9:16:12 PM | | Sheet 1 of 1

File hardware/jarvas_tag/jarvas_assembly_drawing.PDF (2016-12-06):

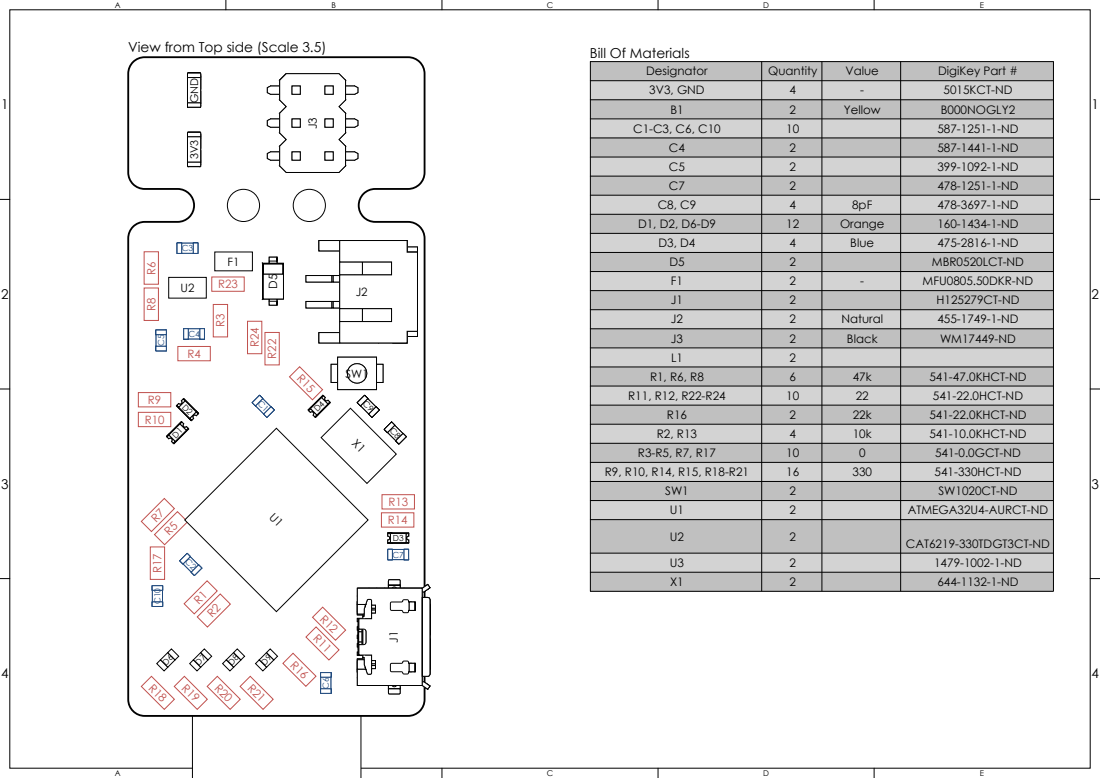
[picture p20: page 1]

View from Top side (Scale 3.5)

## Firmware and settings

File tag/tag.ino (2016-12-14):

#include <SPI.h>
#include "DW1000Ranging.h"
#include "DW1000Device.h"
#include <MatrixMath.h>
#include <math.h>

// If false, then use the calibration. If true, don't use the calibration.
#define CALIBRATE_FIRST false
#define CALIBRATE_SECOND false

//First distance from ground truth 2 meters
//Second from ground truth 5 meters.
#define BEACON_1_FIRSTDIST 2.368
#define BEACON_1_SECONDDIST 5.372

#define USE_MEDIAN_FILT true

#define BEACON_1_ADDRESS 0x1A1A
#define BEACON_2_ADDRESS 0x2A1A
#define BEACON_3_ADDRESS 0x1A3A

#define BEACON_1_X 0.00f
#define BEACON_1_Y 7.01f

#define BEACON_2_X 0.0f
#define BEACON_2_Y 0.0f

#define BEACON_3_X 7.92f
#define BEACON_3_Y 7.92f

//First distance from ground truth 2 meters
//Second from ground truth 5 meters.
#define BEACON_1_FIRSTDIST 2.368
#define BEACON_1_SECONDDIST 5.372
float beacon_1_slope = 3.0f/(BEACON_1_SECONDDIST-BEACON_1_FIRSTDIST);
float beacon_1_offset = 5.0f-(1.0f/beacon_1_slope*BEACON_1_SECONDDIST);

//First distance from ground truth 2 meters
//Second from ground truth 5 meters.
#define BEACON_2_FIRSTDIST 2.368
#define BEACON_2_SECONDDIST 5.372
float beacon_2_slope = 3.0f/(BEACON_2_SECONDDIST-BEACON_2_FIRSTDIST);
float beacon_2_offset = 5.0f-(1.0f/beacon_2_slope*BEACON_2_SECONDDIST);

//First distance from ground truth 2 meters
//Second from ground truth 5 meters.
#define BEACON_3_FIRSTDIST 2.368
#define BEACON_3_SECONDDIST 5.372
float beacon_3_slope = 3.0f/(BEACON_3_SECONDDIST-BEACON_3_FIRSTDIST);
float beacon_3_offset = 5.0f-(1.0f/beacon_3_slope*BEACON_3_SECONDDIST);
//
//#define BEACON_1_OFFSET 0.0368f
//#define BEACON_1_MULTIPLIER 1.0692f
//
//#define BEACON_2_OFFSET 0.6336f
//#define BEACON_2_MULTIPLIER 1.0440f
//
//#define BEACON_3_OFFSET 0.5575f
//#define BEACON_3_MULTIPLIER 1.0666f

// connection pins
const uint8_t PIN_RST = 3; // reset pin
const uint8_t PIN_IRQ = 7; // irq pin
const uint8_t PIN_SS = 10; // spi select pin
volatile unsigned long delaySent = 0;
volatile boolean sentAck = false;
volatile float range = 0;
volatile int address = 0;

volatile float dist[3] = {655.35, 655.35, 655.35};

float beacons[3][2] = {{BEACON_1_X, BEACON_1_Y},
                       {BEACON_2_X, BEACON_2_Y},
                       {BEACON_3_X, BEACON_3_Y}};

float shortestDistanceBeacon1 = 900.0f;
float shortestDistanceBeacon2 = 900.0f;
float shortestDistanceBeacon3 = 900.0f;

float A[3][3];

#define N (5)
struct cir {
    float a[N];
    unsigned h;
    unsigned t;
    unsigned n;
};
typedef volatile struct cir cir_t;

cir_t *cir_new() {
    cir_t *cir = malloc(sizeof(*cir));
    cir->h = 0;
    cir->t = N - 1;
    cir->n = N;
    return cir;
}


// if adding 1 to tail == head, then there is nothing
float cir_empty(cir_t *cir) {
    return (cir->t + 1) % N == cir->h;
}

// if adding 1 to head = tail, then we have no space.
float cir_full(cir_t *cir) {
    return cir->h == cir->t;
}

void cir_enqueue(cir_t *cir, float x) {
    if (cir_full(cir)) cir->t = (cir->t + 1) % N;
    cir->a[cir->h] = x;
    cir->h = (cir->h + 1) % N;
    
    // for(int i = 0; i < N; i++) {
    //     printf("%d ", cir->a[i]);
    // }
    // printf(": %d %d\n", cir->t, cir->h);
}


int compare(const void *x, const void * y) {
    float ix = *(float*)x;
    float iy = *(float*)y;
    return (int)(ix - iy);
}

float cir_median(cir_t *cir) {
    float q[cir->n];
    int qcount = 0;
    // Populate the array
    if(cir_empty(cir)) return 0;
    else if(cir_full(cir)) {
        qcount = cir->n;
        for(int i = 0; i < cir->n; i++) {
            q[i] = cir->a[i];
        }
    } else if(cir->t > cir->h) {
        for(int i = 0; i < cir->h; i++) {
            q[qcount] = cir->a[i];
            qcount++;
        }
        for(int i = cir->t; i < cir->n - 1; i++) {
            q[qcount] = cir->a[i];
            qcount++;
        }
    } else {
        for(int i = cir->t; i < cir->h; i++) {
            q[qcount] = cir->a[i];
            qcount++;
        }
    }
    // Sort the array
    qsort(q, qcount, sizeof(float), compare);
    
    // for(int i = 0; i < qcount; i++) {
    //     printf("%d ", q[i]);
    // }
    // printf("\n");
    
    return q[qcount/2];
}

cir_t *cir1 = cir_new();
cir_t *cir2 = cir_new();
cir_t *cir3 = cir_new();

void setup() {
  Serial.begin(115200);
  delay(1000);
  pinMode(6,OUTPUT);
  
  //init the configuration
  DW1000Ranging.initCommunication(PIN_RST, PIN_SS, PIN_IRQ);
  DW1000Ranging.attachNewRange(newRange);
  DW1000Ranging.startAsTag("7D:00:22:EA:82:60:3B:9C", DW1000.MODE_LONGDATA_RANGE_ACCURACY);
  //DW1000Ranging.useRangeFilter(true);
  unsigned long start, step_start, finished;

  start = micros();
  
  for(int i = 0; i < 3; i++) {
    A[i][0] = -2.0f*beacons[i][0];
    A[i][1] = -2.0f*beacons[i][1];
    A[i][2] = 1.0f;
  }

  Matrix.Invert((float*)A, 3);

  step_start = micros();

  Serial.println(step_start - start);
}
void loop() {
  DW1000Ranging.loop();
}

void newRange() {
    
  address = DW1000Ranging.getDistantDevice()->getShortAddress();

  range = DW1000Ranging.getDistantDevice()->getRange();
  if(range < 0) address = NULL;
  if(address == BEACON_1_ADDRESS){
    range *= CALIBRATE_FIRST||CALIBRATE_SECOND?1.0f:beacon_1_slope;
    range -= CALIBRATE_FIRST||CALIBRATE_SECOND?0.0f:beacon_1_offset;
    
    cir_enqueue(cir1,range);
    dist[0] = (USE_MEDIAN_FILT)?cir_median(cir1):range;
    
    if(CALIBRATE_FIRST||CALIBRATE_SECOND){
      if(dist[0] < shortestDistanceBeacon1 && dist[0] > 0){
        shortestDistanceBeacon1 = dist[0];
      }
    }
  }
  else if(address == BEACON_2_ADDRESS){
    range *= CALIBRATE_FIRST||CALIBRATE_SECOND?1.0f:beacon_2_slope;
    range -= CALIBRATE_FIRST||CALIBRATE_SECOND?0.0f:beacon_2_offset;
    cir_enqueue(cir2,range);
    dist[1] = (USE_MEDIAN_FILT)?cir_median(cir2):range;
    
    if(CALIBRATE_FIRST||CALIBRATE_SECOND){
      if(dist[1] < shortestDistanceBeacon2 && dist[1] > 0){
        shortestDistanceBeacon2 = dist[1];
      }
    }
  }
  else if(address == BEACON_3_ADDRESS){
    range *= CALIBRATE_FIRST||CALIBRATE_SECOND?1.0f:beacon_3_slope;
    range -= CALIBRATE_FIRST||CALIBRATE_SECOND?0.0f:beacon_3_offset;
    cir_enqueue(cir3,range);
    dist[2] = (USE_MEDIAN_FILT)?cir_median(cir3):range;
    
    if(CALIBRATE_FIRST||CALIBRATE_SECOND){
      if(dist[2] < shortestDistanceBeacon3 && dist[2] > 0){
        shortestDistanceBeacon3 = dist[2];
      }
    }
  }
  Serial.print("1: ");Serial.print(dist[0]);Serial.print(" 2: ");Serial.print(dist[1]);Serial.print(" 3: ");Serial.print(dist[2]);
  
  // ITERATIVE STEPS BELOW

  float y[3];
  for(int i = 0; i < 3; i++) {
    y[i] = float((dist[i])*(dist[i]) - (beacons[i][0])*(beacons[i][0]) - (beacons[i][1])*(beacons[i][1]));
  }
  float x[3];
  Matrix.Multiply((float*)A, (float*)y, 3, 3, 1, (float*)x);

  float estimate[2] = {x[0], x[1]};

  Serial.print(" Location: ["); Serial.print(estimate[0]); Serial.print("m, "); Serial.print(estimate[1]); Serial.print("m] \n");
  
  if(estimate[0] > 4.0f){
    digitalWrite(6,HIGH);
  }
  else digitalWrite(6,LOW);

  DW1000Ranging.setLoc(estimate[0], estimate[1]);
}

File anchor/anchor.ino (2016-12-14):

#include <SPI.h>
#include "DW1000Ranging.h"
#include "DW1000Device.h"

// connection pins
const uint8_t PIN_RST = 3; // reset pin
const uint8_t PIN_IRQ = 7; // irq pin
const uint8_t PIN_SS = 10; // spi select pin

void setup() {
  // Serial is for communication between the computer and the board.
  Serial.begin(115200);
  delay(1000);
  DW1000Ranging.initCommunication(PIN_RST, PIN_SS, PIN_IRQ);
  DW1000Ranging.attachNewRange(newRange);
  DW1000Ranging.startAsAnchor("3A:1A:1A:1A:1A:1A:1A:1A", DW1000.MODE_LONGDATA_RANGE_ACCURACY);
}

void loop() {
  DW1000Ranging.loop();

  Serial.print(DW1000Ranging.getTagX());
  Serial.print(" ");
  Serial.println(DW1000Ranging.getTagY());
  if(DW1000Ranging.getTagY() > 4.0f){
    digitalWrite(6,HIGH);
  }
  else digitalWrite(6,LOW);
}

void newRange() {
  // Empty.  
}

// 23 26 3

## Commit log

2016-12-06 adding anchor and custom DW1000 library
    [AdapterBoardTestBed.fzz, adapterBoard.fzz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]
2016-12-06 Added Calibration Routines
2016-12-06 Hardware design files and programming instructions
    [dwm1000arduino.GBL, dwm1000arduino.GBO, dwm1000arduino.GBP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]
2016-12-13 Updated calibration code
2016-12-13 Fixed transmission of negative location values
    [tag.ino]
2016-12-13 Print out range info
2016-12-13 Median filter enable/disable
2016-12-14 Filtering and algorithm documentation
2016-12-14 Updated Calibration Steps
2016-12-14 Added 3D Files
    [jarvas_box lid.STL, jarvas_box.STL, jarvas_stand.STL]
